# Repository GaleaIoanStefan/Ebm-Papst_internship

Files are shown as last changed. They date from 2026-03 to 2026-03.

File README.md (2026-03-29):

# Ebm-Papst_internship
This project contains the PCB design for a equipment that measures contact heat transfer rates.

# The Block Diagram of the Project



In here we can see the main parts of the project namely the supply, a feedback control loop of the ventilator and another feedback control loop of the metal plate. Everything that is contained in the colored frame sits on the actual PCB.

An Arduino Nano Esp32 microcontroller is the brain of the board, which will control the speed of the fan on the left of the schematic with a voltage switch, through a Hall speed sensor to complete a feedback loop. Similarly, on the right side, the esp32 will control the temperature of a hob with a 120W resistor with a voltage switch, and the feedback communication is done by 2 NTC thermistors

The tool used in this project was KiCad 9.0

# The electrical schematic of the PCB



# The layout of the PCB



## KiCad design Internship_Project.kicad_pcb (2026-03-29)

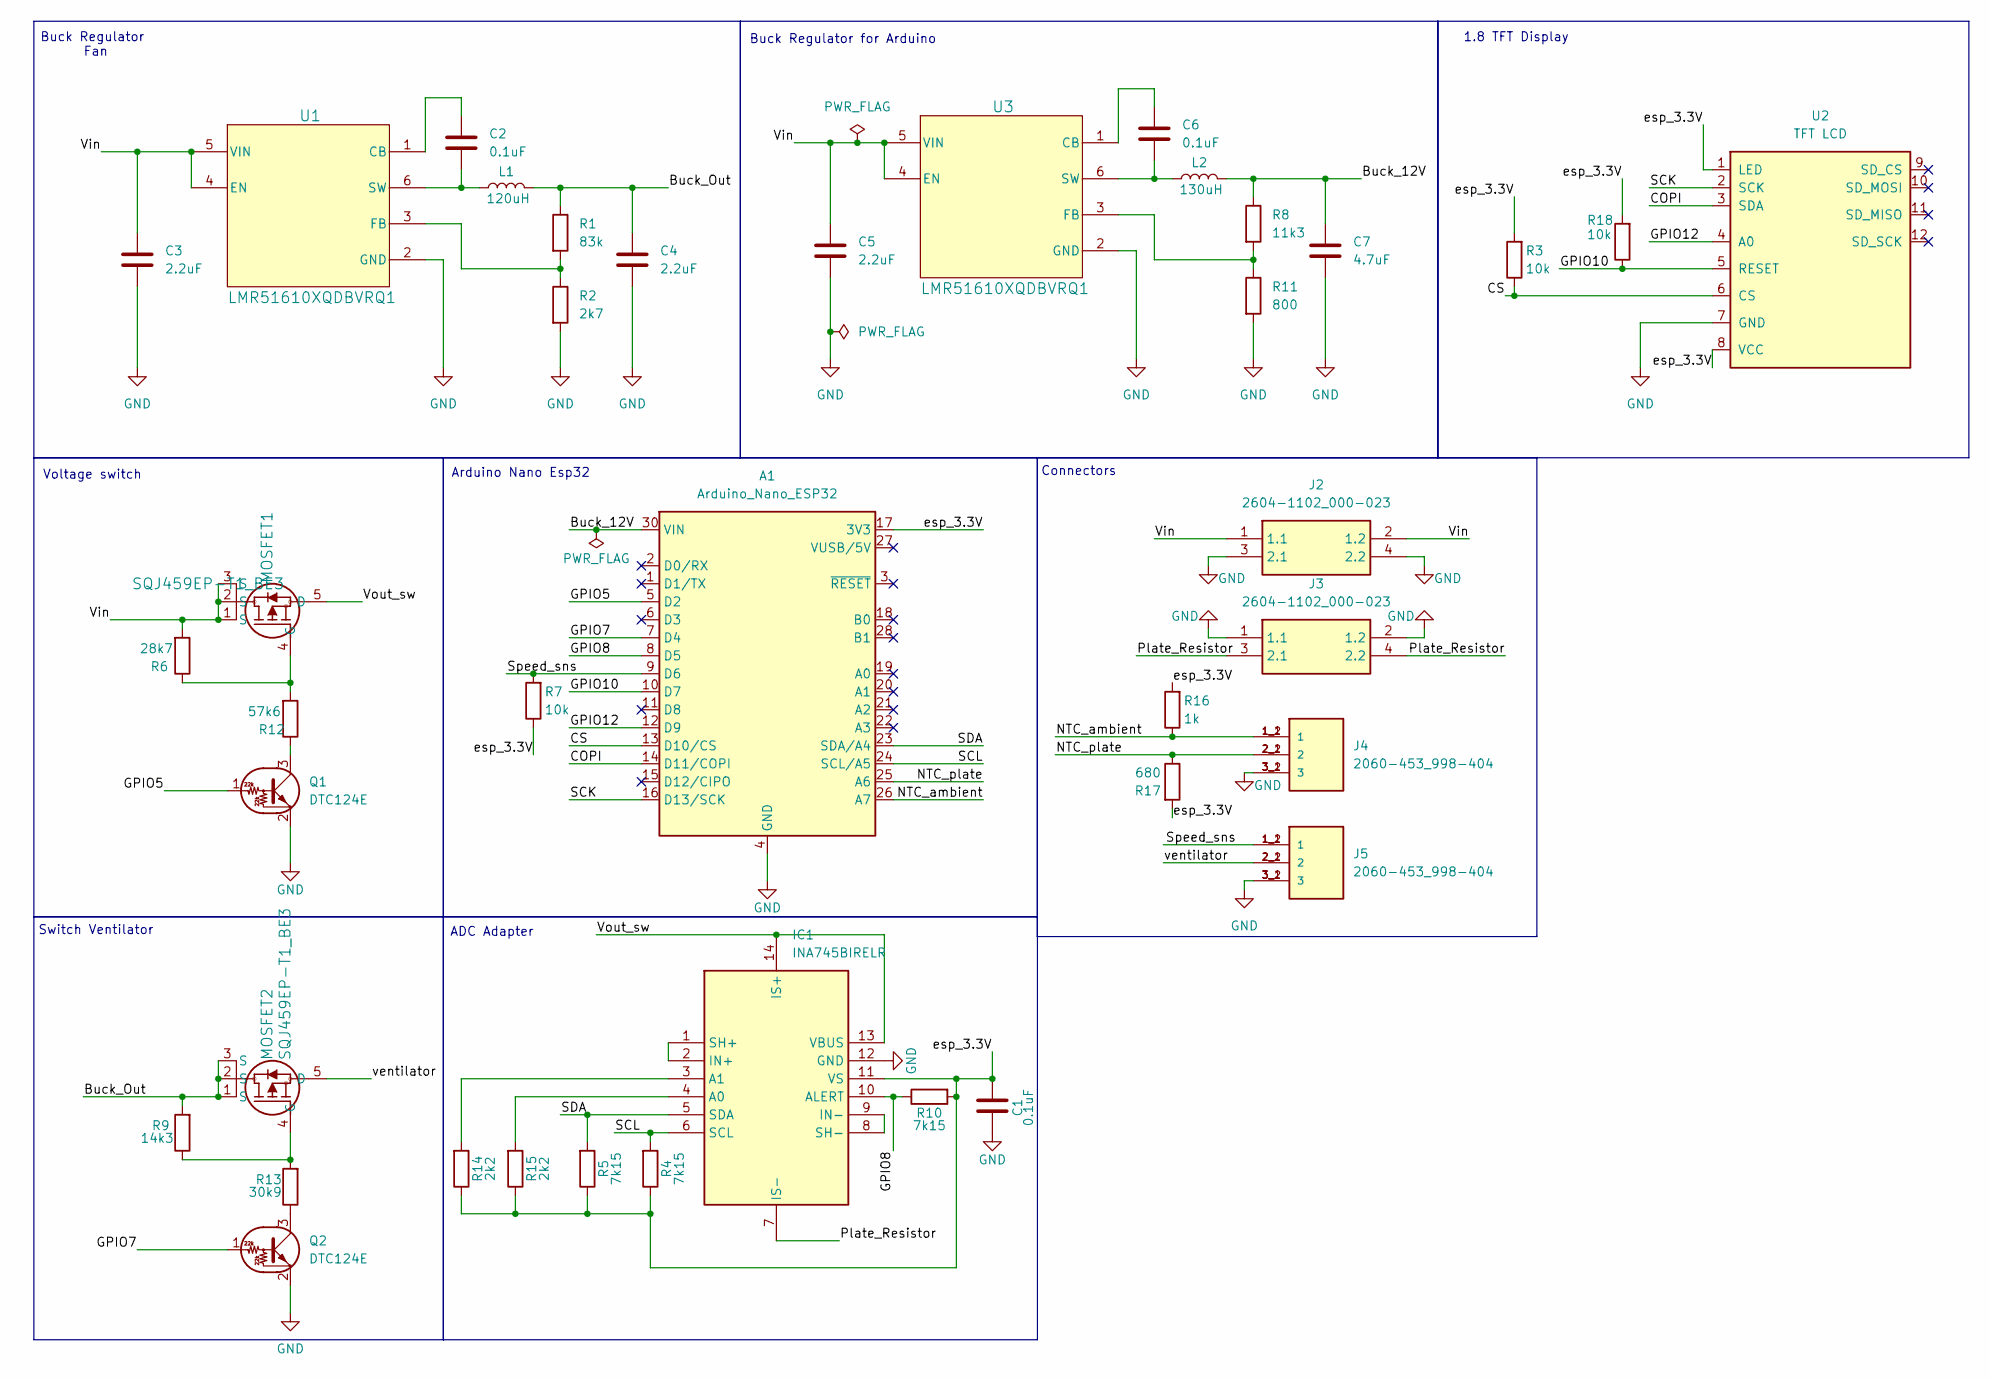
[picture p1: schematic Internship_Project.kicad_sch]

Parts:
A1: Arduino_Nano_ESP32; Arduino_Nano_WithMountingHoles
C1, C2, C6: 0.1uF; C_0805_2012Metric
C3, C4, C5: 2.2uF; C_1206_3216Metric
C7: 4.7uF; C_1206_3216Metric
IC1: INA745BIRELR; Manufacturer_Part_Number INA745BIRELR; Mouser Part Number 595-INA745BIRELR
J2, J3: 2604-1102_000-023; 26041102000023; Manufacturer_Part_Number 2604-1102/000-023
J4, J5: 2060-453_998-404; WAGO_2060-453_998-404; PARTREV N/A
L1: 120uH; L_1210_3225Metric
L2: 130uH; L_1210_3225Metric
MOSFET1, MOSFET2: SQJ459EP-T1_BE3; TO_0EP-T1_BE3_VIS
Q1, Q2: DTC124E; SOT-23
R1: 83k; R_0603_1608Metric
R2: 2k7; R_0603_1608Metric
R3, R7, R18: 10k; R_0603_1608Metric
R4, R5, R10: 7k15; R_0603_1608Metric
R6: 28k7; R_0603_1608Metric
R8: 11k3; R_0603_1608Metric
R9: 14k3; R_0603_1608Metric
R11: 800; R_0603_1608Metric
R12: 57k6; R_0603_1608Metric
R13: 30k9; R_0603_1608Metric
R14, R15: 2k2; R_0603_1608Metric
R16: 1k; R_0603_1608Metric
R17: 680; R_0603_1608Metric
U1, U3: LMR51610XQDBVRQ1; DBV0006A-IPC_A
U2: TFT LCD; TFT LCD 1.8inch 128x160 w_ SD Card Slot

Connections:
/Buck_12V: A1.30 (VIN), C7.1, L2.2, R8.1
/Buck_Out: C4.1, L1.2, MOSFET2.1 (S), MOSFET2.2 (S), MOSFET2.3 (S), R1.1, R9.2
/COPI: A1.14 (D11/COPI), U2.3 (SDA)
/CS: A1.13 (D10/CS), R3.1, U2.6 (CS)
/GPIO5: A1.5 (D2), Q1.1 (B)
/GPIO7: A1.7 (D4), Q2.1 (B)
/GPIO8: A1.8 (D5), IC1.10 (ALERT), R10.1
/GPIO10: A1.10 (D7), R18.1, U2.5 (RESET)
/GPIO12: A1.12 (D9), U2.4 (A0)
/NTC_ambient: A1.26 (A7), J4.1_1 (1), J4.1_2 (1), R16.1
/NTC_plate: A1.25 (A6), J4.2_1 (2), J4.2_2 (2), R17.1
/Plate_Resistor: IC1.7 (IS-), J3.3 (2.1), J3.4 (2.2)
/SCK: A1.16 (D13/SCK), U2.2 (SCK)
/SCL: A1.24 (SCL/A5), IC1.6 (SCL), R4.2
/SDA: A1.23 (SDA/A4), IC1.5 (SDA), R5.2
/Speed_sns: A1.9 (D6), J5.1_1 (1), J5.1_2 (1), R7.2
/Vin: C3.1, C5.1, J2.1 (1.1), J2.2 (1.2), MOSFET1.1 (S), MOSFET1.2 (S), MOSFET1.3 (S), R6.2, U1.4 (EN), U1.5 (VIN), U3.4 (EN), U3.5 (VIN)
/Vout_sw: IC1.13 (VBUS), IC1.14 (IS+), MOSFET1.5 (D)
/esp_3.3V: A1.17 (3V3), C1.1, IC1.11 (VS), R3.2, R4.1, R5.1, R7.1, R10.2, R14.1, R15.1, R16.2, R17.2, R18.2, U2.1 (LED), U2.8 (VCC)
/ventilator: J5.2_1 (2), J5.2_2 (2), MOSFET2.5 (D)
GND: A1.4 (GND), A1.29 (GND), C1.2, C3.2, C4.2, C5.2, C7.2, IC1.12 (GND), J2.3 (2.1), J2.4 (2.2), J3.1 (1.1), J3.2 (1.2), J4.3_1 (3), J4.3_2 (3), J5.3_1 (3), J5.3_2 (3), Q1.2 (E), Q2.2 (E), R2.2, R11.2, U1.2 (GND), U2.7 (GND), U3.2 (GND)
unnamed: IC1.4 (A0), R15.2
unnamed: IC1.3 (A1), R14.2
unnamed: IC1.1 (SH+), IC1.2 (IN+)
unnamed: IC1.8 (SH-), IC1.9 (IN-)
unnamed: MOSFET1.4 (G), R6.1, R12.2
unnamed: MOSFET2.4 (G), R9.1, R13.2
unnamed: Q1.3 (C), R12.1
unnamed: Q2.3 (C), R13.1
unnamed: C2.1, U1.1 (CB)
unnamed: R1.2, R2.1, U1.3 (FB)
unnamed: C2.2, L1.1, U1.6 (SW)
unnamed: C6.1, U3.1 (CB)
unnamed: R8.2, R11.1, U3.3 (FB)
unnamed: C6.2, L2.1, U3.6 (SW)

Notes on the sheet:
Buck Regulator Fan
1.8 TFT Display
Switch Ventilator
ADC Adapter
Arduino Nano Esp32
Voltage switch
Connectors
Buck Regulator for Arduino

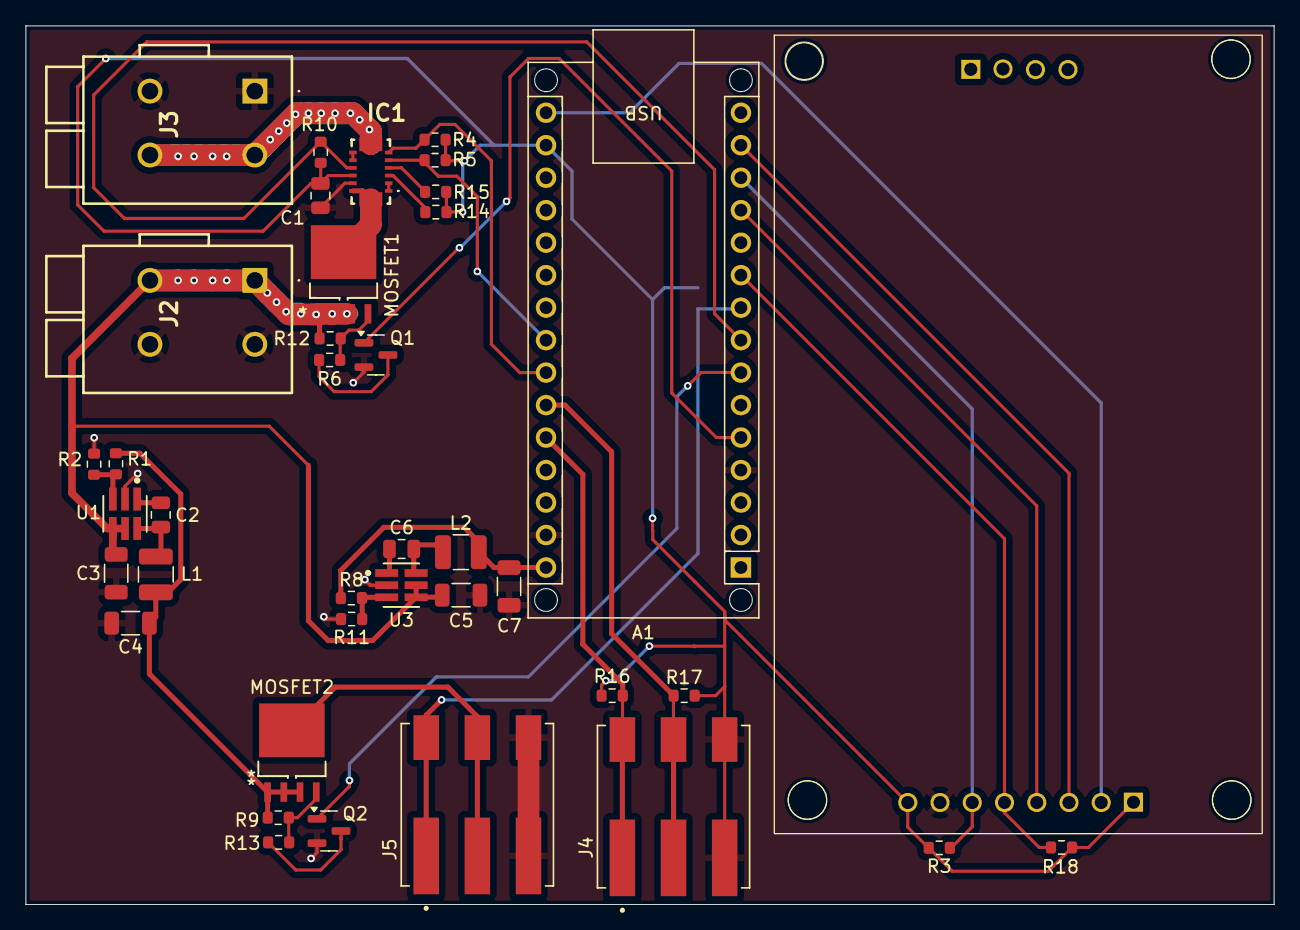
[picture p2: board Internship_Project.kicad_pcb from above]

Board: 2 copper layers, 97.6 x 68.7 mm, 40 parts (1 on the bottom side), 35 nets.

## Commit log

2026-03-29 Update README with PCB layout information
    Added PCB layout section and image to README.
2026-03-29 Document tool used in project as KiCad 9.0
    Added information about the tool used for the project.
2026-03-29 Update PCB schematic image in README
